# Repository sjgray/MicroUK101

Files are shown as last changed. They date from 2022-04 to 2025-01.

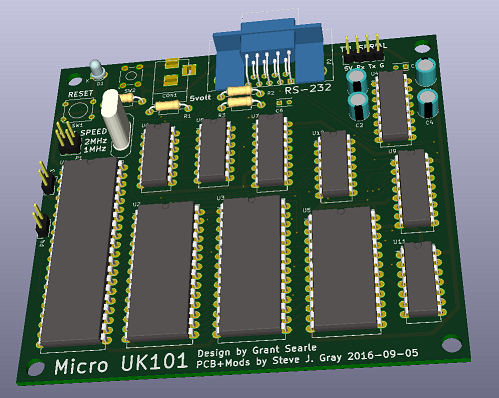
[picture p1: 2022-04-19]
Pics/MicroUK101.png

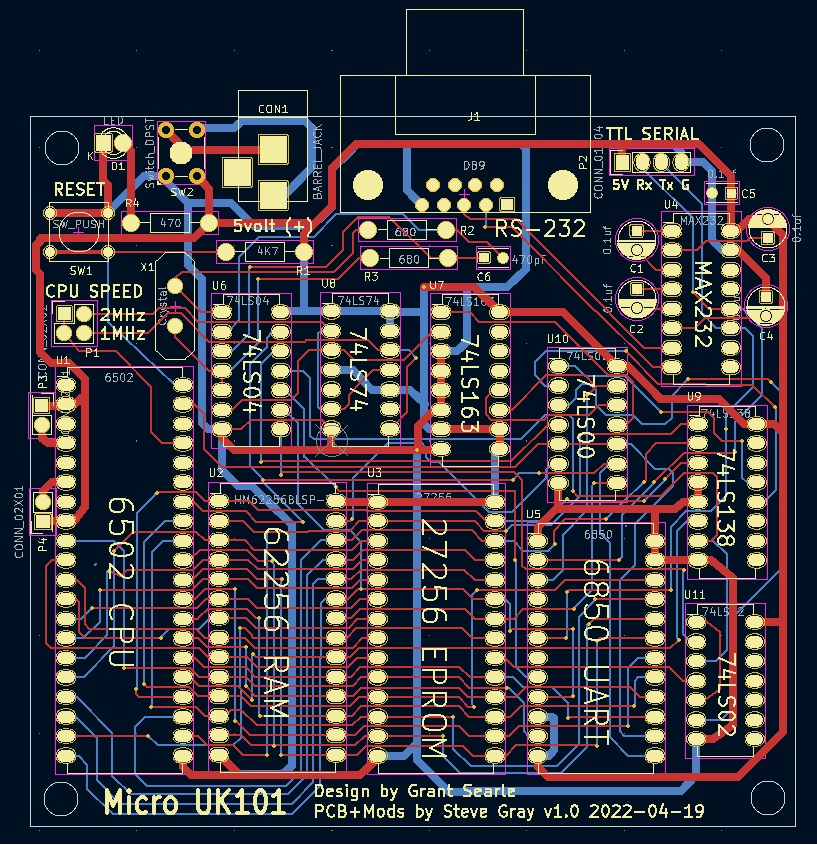
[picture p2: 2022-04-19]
Pics/MicroUK101-routed-2022-04-19.png

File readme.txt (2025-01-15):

MicroUK101
==========

 This is a project to design a board for Grant Searle's Micro UK-101 design.
I started this in 2016 when I was very new at electronics and Kicad.
As I was interested in 6502 and OSI machines I picked this as something to
learn a bit of both things. When I finished the design in Sept 2016 I
ultimately decided not to make boards as I felt I would not really use the
board for anything serious. But it helped spur my interest in designing
more boards. I published the project on my web page and mostly forgot about
it.

 In 2022 I was contacted by someone interested in making the board so I
sent them all the files. Well, they made a run and the board worked with
only one (important) mistake... The power connector was backwards. So, I
have decided to fix that and update a few thing using the latest Kicad
and to put the files on Github for anyone interested in making their own
boards.

You can find my project webpage here:

http://www.cbmsteve.ca/microuk101/index.html

Gerbers files can be found in the Gerbers directory. I have not actually
made boards from these files, so use at your own risk!

Steve

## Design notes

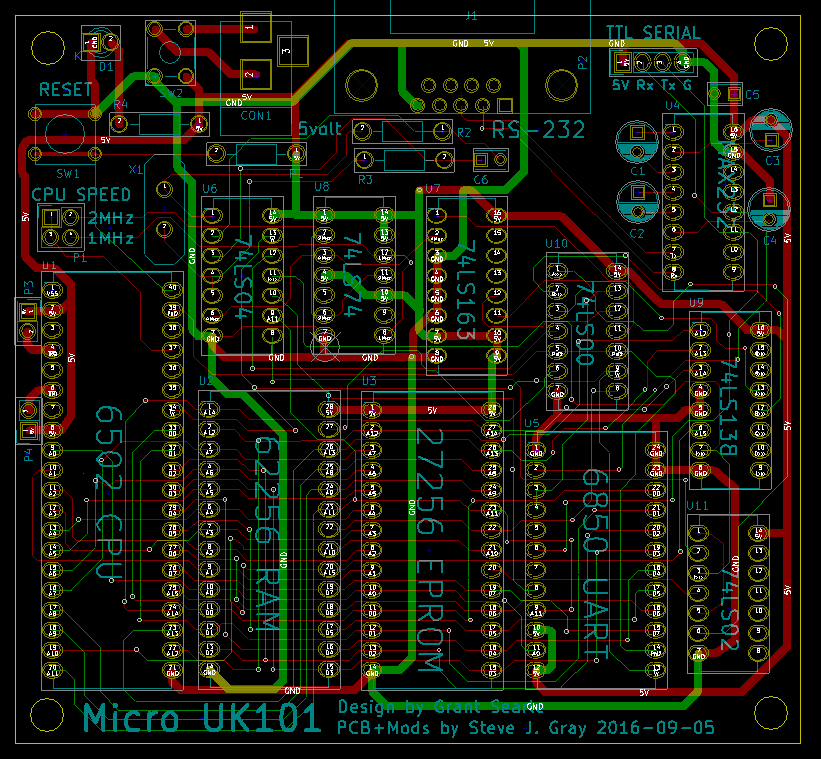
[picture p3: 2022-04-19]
Pics/MicroUK101-routed-2016-09-05.png

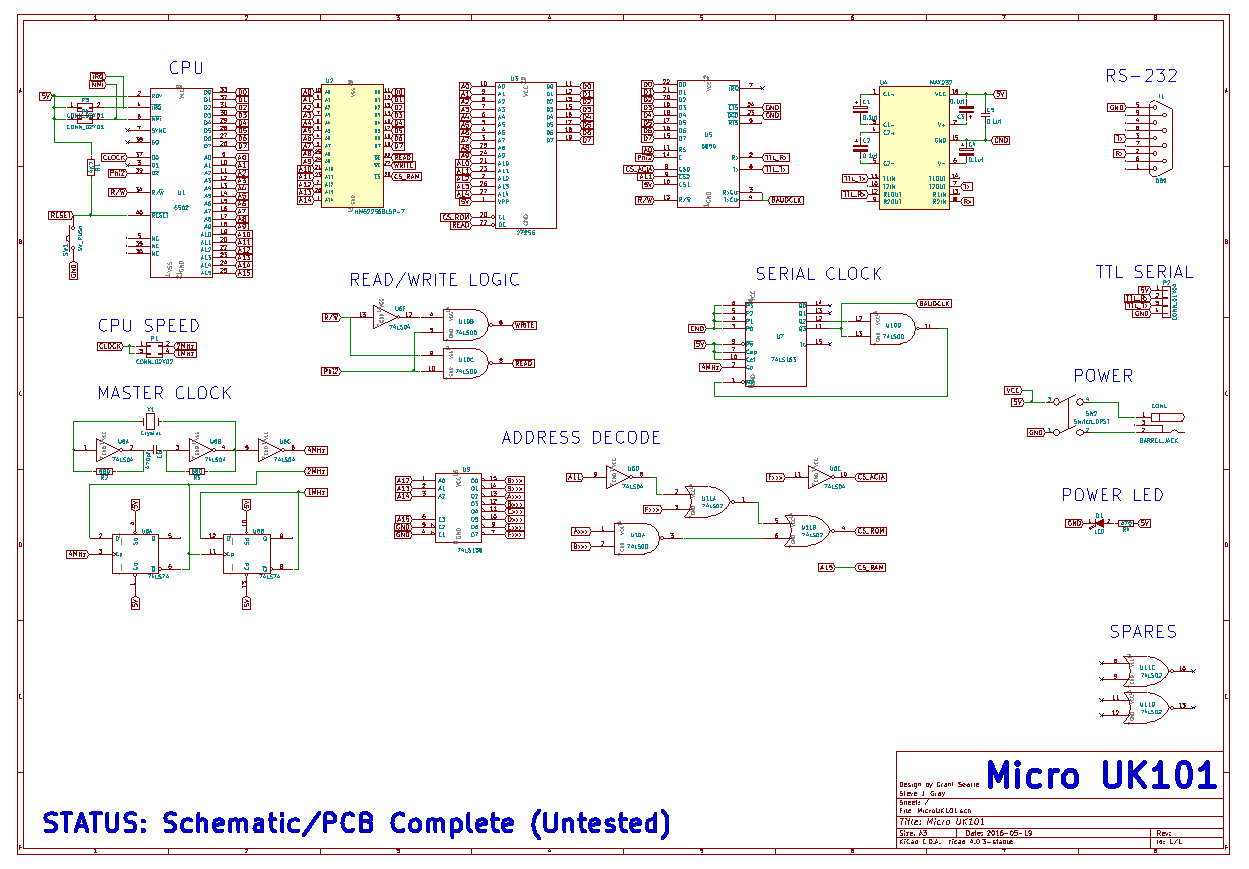
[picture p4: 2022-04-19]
Pics/MicroUK101-schem-2016-09-05.png

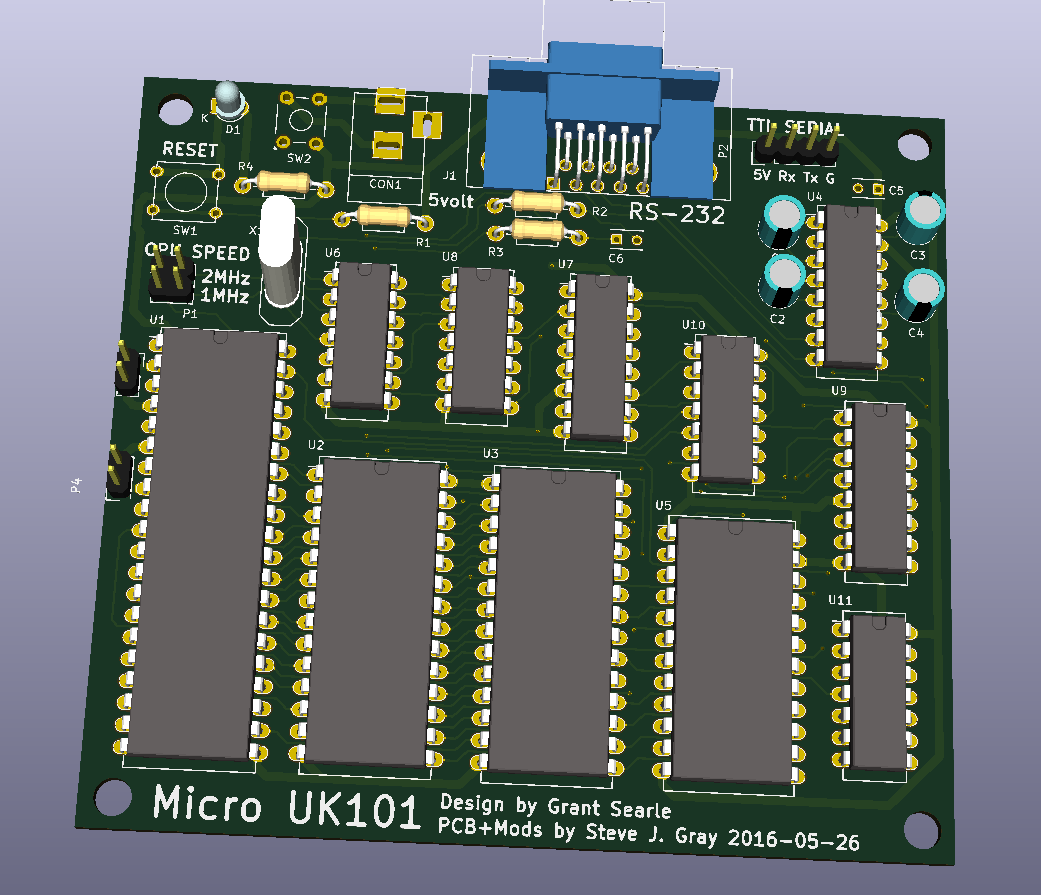
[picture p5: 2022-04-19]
Pics/MicroUK101-pic-2016-06-06.png

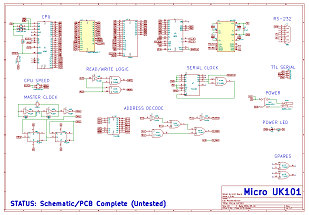
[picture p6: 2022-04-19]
Pics/MicroUK101-schem-sm-2016-09-05.png

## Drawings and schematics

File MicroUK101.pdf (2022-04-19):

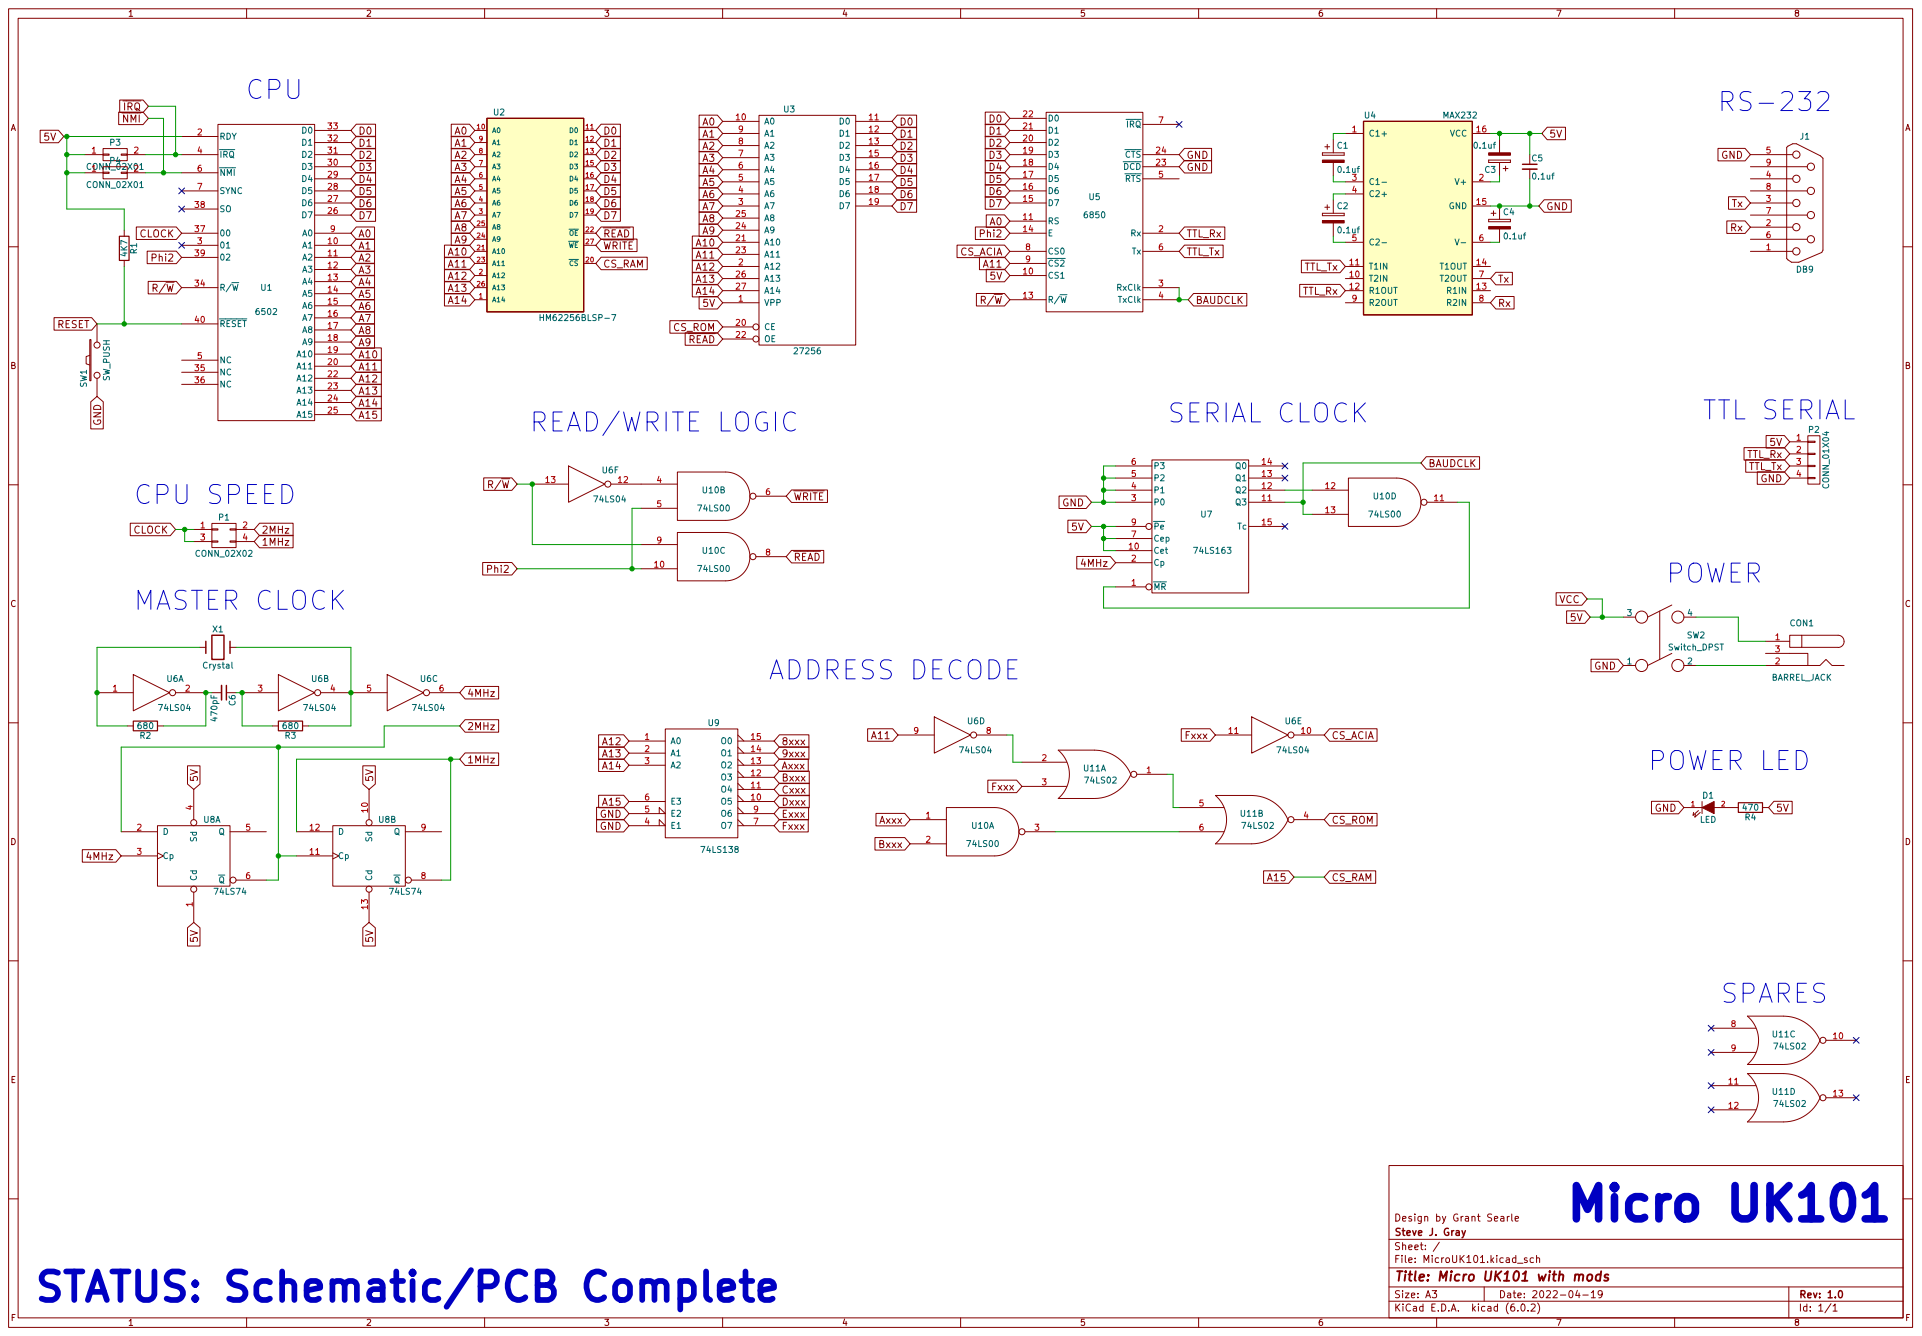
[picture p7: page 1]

TTL SERIAL READ/WRITE LOGIC

Design by Grant Searle
File: MicroUK101.kicad_sch Sheet: / Steve J. Gray

STATUS: Schematic/PCB Complete

Id: 1/1 Title: Micro UK101 with mods

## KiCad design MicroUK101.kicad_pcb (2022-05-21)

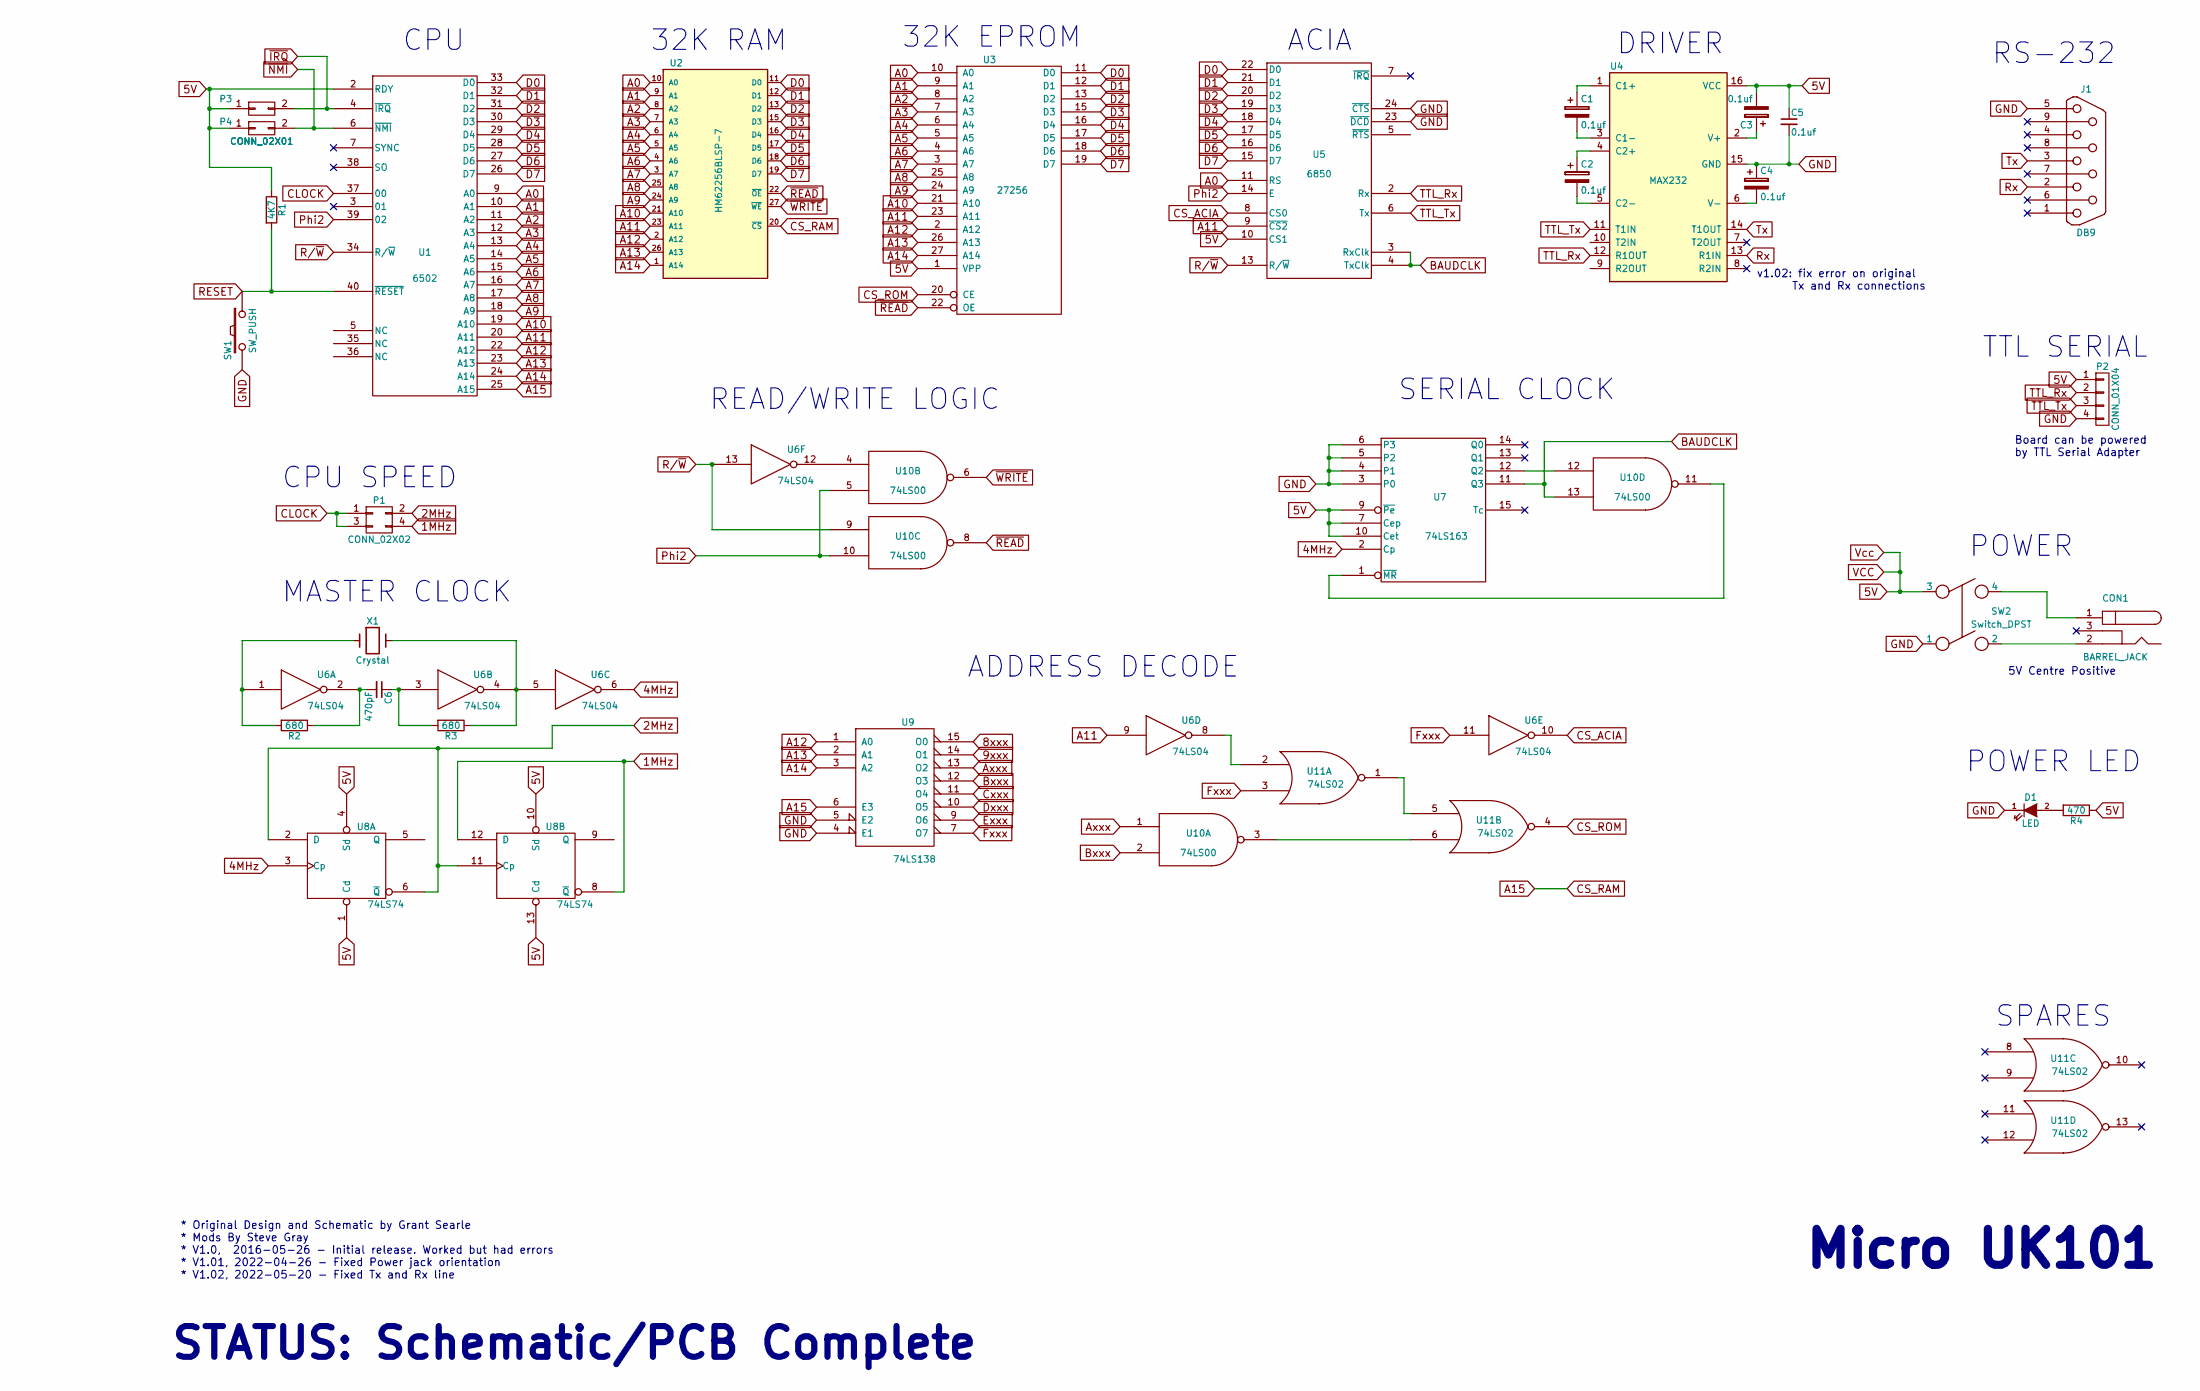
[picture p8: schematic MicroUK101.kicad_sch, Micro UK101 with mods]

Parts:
C1, C2, C3, C4: 0.1uf; C_Radial_D5_L6_P2.5
C5: 0.1uf; C_Rect_L4_W2.5_P2.5
C6: 470pF; C_Rect_L4_W2.5_P2.5
CON1: BARREL_JACK
D1: LED; LED-3MM
J1: DB9; DB9MC
P1: CONN_02X02; Pin_Header_Straight_2x02
P2: CONN_01X04; Pin_Header_Straight_1x04
P3, P4: CONN_02X01; Pin_Header_Straight_2x01
R1: 4K7; Resistor_Horizontal_RM10mm
R2, R3: 680; Resistor_Horizontal_RM10mm
R4: 470; Resistor_Horizontal_RM10mm
SW1: SW_PUSH; SW_PUSH_SMALL
SW2: Switch_DPST; SW_TH_Tactile_Omron_B3F-10xx
U1: 6502; DIP-40_W15.24mm_LongPads
U2: HM62256BLSP-7; DIP-28_W15.24mm_LongPads
U3: 27256; DIP-28_W15.24mm_LongPads
U4: MAX232; DIP-16_W7.62mm_LongPads
U5: 6850; DIP-24_W15.24mm_LongPads
U6: 74LS04; DIP-14_W7.62mm_LongPads
U7: 74LS163; DIP-16_W7.62mm_LongPads
U8: 74LS74; DIP-14_W7.62mm_LongPads
U9: 74LS138; DIP-16_W7.62mm_LongPads
U10: 74LS00; DIP-14_W7.62mm_LongPads
U11: 74LS02; DIP-14_W7.62mm_LongPads
X1: Crystal; HC-18UV

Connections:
1MHz: P1.4, U8.8 (~Q), U8.12 (D)
2MHz: P1.2, U8.2 (D), U8.6 (~Q), U8.11 (Cp)
4MHz: U6.6, U7.2 (Cp), U8.3 (Cp)
5V: C3.2, C5.1, P2.1, P3.1, P4.1, R1.1, R4.1, SW2.3, U1.2 (RDY), U1.8 (Vcc), U2.28 (VCC), U3.1 (VPP), U3.28 (VCC), U4.16 (VCC), U5.10 (CS1), U5.12 (Vcc), U6.14 (VCC), U7.7 (Cep), U7.9 (~Pe), U7.10 (Cet), U7.16 (VCC), U8.1 (Cd), U8.4 (Sd), U8.10 (Sd), U8.13 (Cd), U8.14 (VCC), U9.16 (VCC), U10.14 (VCC), U11.14 (VCC)
8xxx: U9.15 (O0)
9xxx: U9.14 (O1)
A0: U1.9 (A0), U2.10 (A0), U3.10 (A0), U5.11 (RS)
A1: U1.10 (A1), U2.9 (A1), U3.9 (A1)
A2: U1.11 (A2), U2.8 (A2), U3.8 (A2)
A3: U1.12 (A3), U2.7 (A3), U3.7 (A3)
A4: U1.13 (A4), U2.6 (A4), U3.6 (A4)
A5: U1.14 (A5), U2.5 (A5), U3.5 (A5)
A6: U1.15 (A6), U2.4 (A6), U3.4 (A6)
A7: U1.16 (A7), U2.3 (A7), U3.3 (A7)
A8: U1.17 (A8), U2.25 (A8), U3.25 (A8)
A9: U1.18 (A9), U2.24 (A9), U3.24 (A9)
A10: U1.19 (A10), U2.21 (A10), U3.21 (A10)
A11: U1.20 (A11), U2.23 (A11), U3.23 (A11), U5.9 (~CS2), U6.9
A12: U1.22 (A12), U2.2 (A12), U3.2 (A12), U9.1 (A0)
A13: U1.23 (A13), U2.26 (A13), U3.26 (A13), U9.2 (A1)
A14: U1.24 (A14), U2.1 (A14), U3.27 (A14), U9.3 (A2)
A15: U1.25 (A15), U2.20 (~CS), U9.6 (E3)
Axxx: U9.13 (O2), U10.1
BAUDCLK: U5.3 (RxClk), U5.4 (TxClk), U7.11 (Q3), U10.13
Bxxx: U9.12 (O3), U10.2
CLOCK: P1.1, P1.3, U1.37 (00)
CS_ACIA: U5.8 (CS0), U6.10
CS_ROM: U3.20 (CE), U11.4
Cxxx: U9.11 (O4)
D0: U1.33 (D0), U2.11 (D0), U3.11 (D0), U5.22 (D0)
D1: U1.32 (D1), U2.12 (D1), U3.12 (D1), U5.21 (D1)
D2: U1.31 (D2), U2.13 (D2), U3.13 (D2), U5.20 (D2)
D3: U1.30 (D3), U2.15 (D3), U3.15 (D3), U5.19 (D3)
D4: U1.29 (D4), U2.16 (D4), U3.16 (D4), U5.18 (D4)
D5: U1.28 (D5), U2.17 (D5), U3.17 (D5), U5.17 (D5)
D6: U1.27 (D6), U2.18 (D6), U3.18 (D6), U5.16 (D6)
D7: U1.26 (D7), U2.19 (D7), U3.19 (D7), U5.15 (D7)
Dxxx: U9.10 (O5)
Exxx: U9.9 (O6)
Fxxx: U6.11, U9.7 (O7), U11.3
GND: C4.1, C5.2, D1.1 (K), J1.5, P2.4, SW1.2, SW2.1, U1.21 (GND), U2.14 (GND), U3.14 (GND), U4.15 (GND), U5.1 (GND), U5.23 (~DCD), U5.24 (~CTS), U6.7 (GND), U7.3 (P0), U7.4 (P1), U7.5 (P2), U7.6 (P3), U7.8 (GND), U8.7 (GND), U9.4 (E1), U9.5 (E2), U9.8 (GND), U10.7 (GND), U11.7 (GND)
unnamed: C1.1, U4.1 (C1+)
unnamed: C1.2, U4.3 (C1-)
unnamed: C2.1, U4.4 (C2+)
unnamed: C2.2, U4.5 (C2-)
unnamed: C3.1, U4.2 (V+)
unnamed: C4.2, U4.6 (V-)
unnamed: C6.1, R3.2, U6.3
unnamed: C6.2, R2.1, U6.2
unnamed: CON1.1, SW2.4
unnamed: CON1.2, SW2.2
unnamed: D1.2 (A), R4.2
unnamed: R2.2, U6.1, X1.1
unnamed: R3.1, U6.4, U6.5, X1.2
unnamed: U10.3, U11.6
unnamed: U6.12, U10.4
unnamed: U7.1 (~MR), U10.11
unnamed: U7.12 (Q2), U10.12
unnamed: U11.1, U11.5
unnamed: U6.8, U11.2
Phi2: U1.39 (02), U5.14 (E), U10.5, U10.10
RESET: R1.2, SW1.1, U1.40 (~RESET)
Rx: J1.2, U4.13 (R1IN)
R/~W: U1.34 (R/~W), U5.13 (R/~W), U6.13, U10.9
TTL_Rx: P2.2, U4.12 (R1OUT), U5.2 (Rx)
TTL_Tx: P2.3, U4.11 (T1IN), U5.6 (Tx)
Tx: J1.3, U4.14 (T1OUT)
VSS: U1.1 (VSS)
~IRQ: P3.2, U1.4 (~IRQ)
~NMI: P4.2, U1.6 (~NMI)
~READ: U2.22 (~OE), U3.22 (OE), U10.8
~WRITE: U2.27 (~WE), U10.6

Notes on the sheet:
Micro UK101
CPU
POWER
READ/WRITE LOGIC
* Original Design and Schematic by Grant Searle * Mods By Steve Gray * V1.0, 2016-05-26 - Initial release. Worked but had errors * V1.01, 2022-04-26 - Fixed Power jack orientation * V1.02, 2022-05-20 - Fixed Tx and Rx line
MASTER CLOCK
DRIVER
STATUS: Schematic/PCB Complete
32K EPROM
Board can be powered by TTL Serial Adapter
SPARES
POWER LED
TTL SERIAL
RS-232
ACIA
ADDRESS DECODE
32K RAM
SERIAL CLOCK
v1.02: fix error on original Tx and Rx connections
5V Centre Positive
CPU SPEED

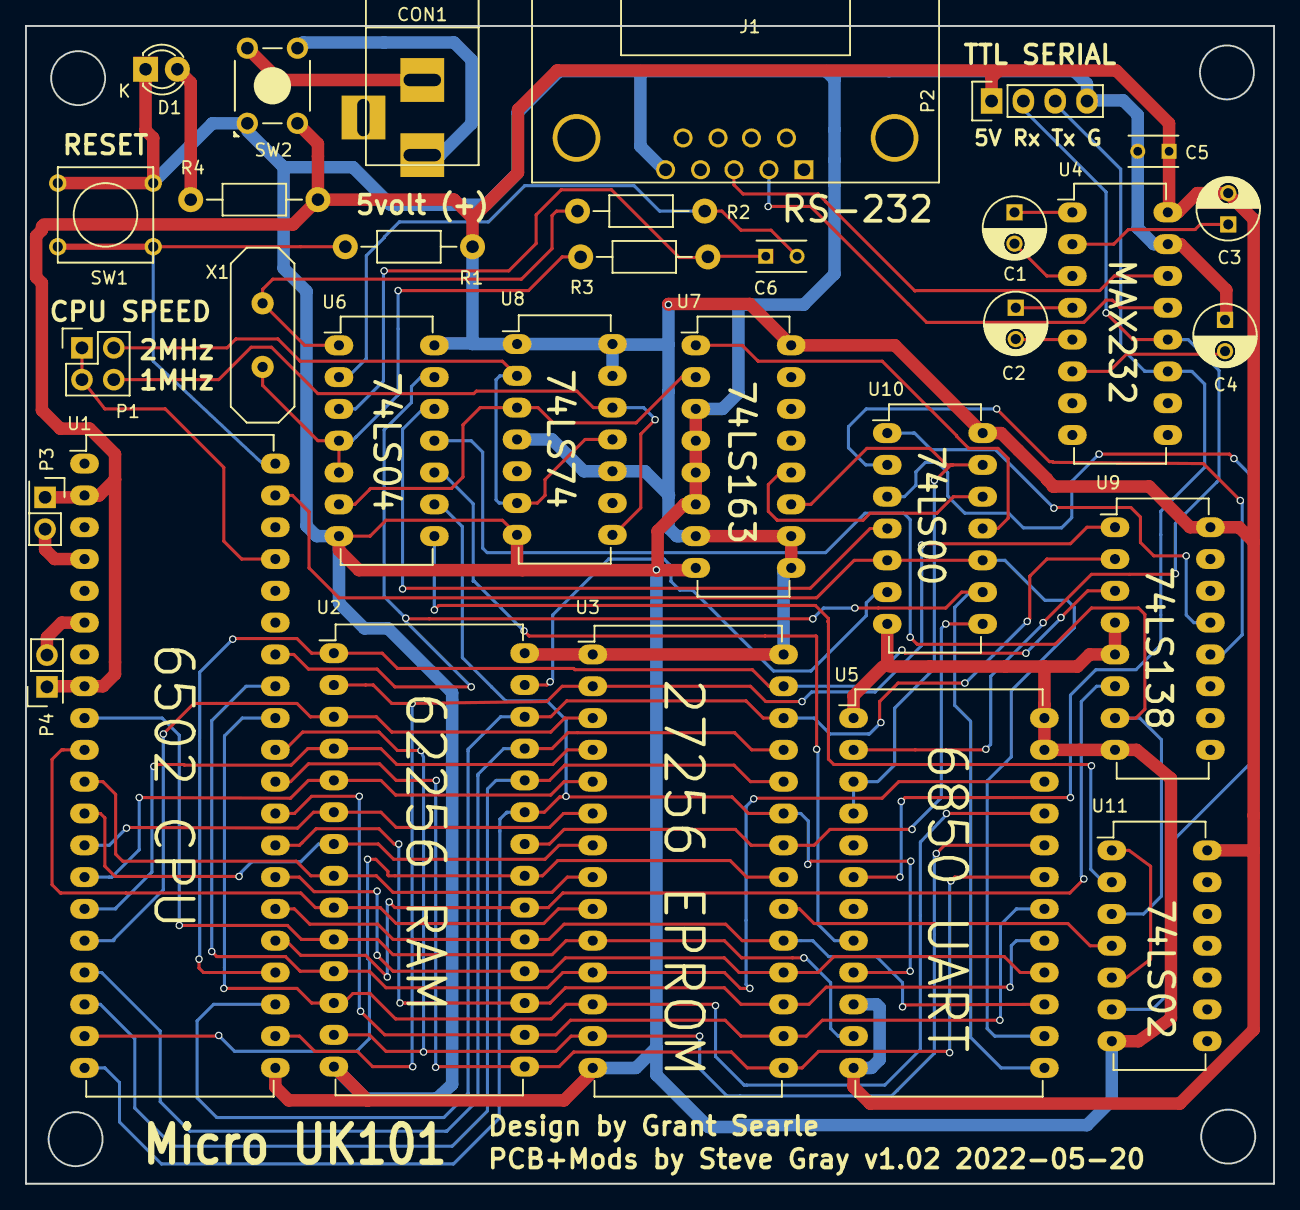
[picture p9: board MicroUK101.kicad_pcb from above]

Board: 2 copper layers, 99.7 x 92.5 mm, 31 parts (0 on the bottom side), 66 nets.

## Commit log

2022-04-19 Initial V1.0 release
    This was designed in 2016 but never officially released. I have
    corrected a few things and saved the files in the latest Kicad v6.
    Gerbers are included. The schematic design was verified working, however
    the inital pcb had an error with the power connector orientation. That
    has been fixed. Gerbers have not been verified so USE AT OWN RISK!
    [MicroUK101-2018-11-13-08-30-21.sch, MicroUK101-2022-04-19-16-03-08.sch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]
2022-04-25 Update to add missing gerber files
    Solder Masks now included.
    [MicroUK101-2018-11-13-08-30-21.sch, MicroUK101-2022-04-19-16-03-08.sch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]
2022-04-25 Clean up a big mess
    Gerbers directory should have the correct files now.
    Backup contains only zipped backup. Removed many duplicates. Sorry.
    [MicroUK101-2018-11-13-08-30-21.sch, MicroUK101-2022-04-19-16-03-08.sch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]
2022-05-21 Release 1.02
    Fix Tx and Rx lines to RS-232. Ran DRC and fixed a bunch of small track
    errors. Updated silkscreen, created new gerbers.
    [MicroUK101-B_Cu.gbr, MicroUK101-B_Mask.gbr, MicroUK101-B_Silkscreen.gbr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]
